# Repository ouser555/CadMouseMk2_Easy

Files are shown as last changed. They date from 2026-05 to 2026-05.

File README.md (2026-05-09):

# CAD Mouse MK2

Watch the build video ↓

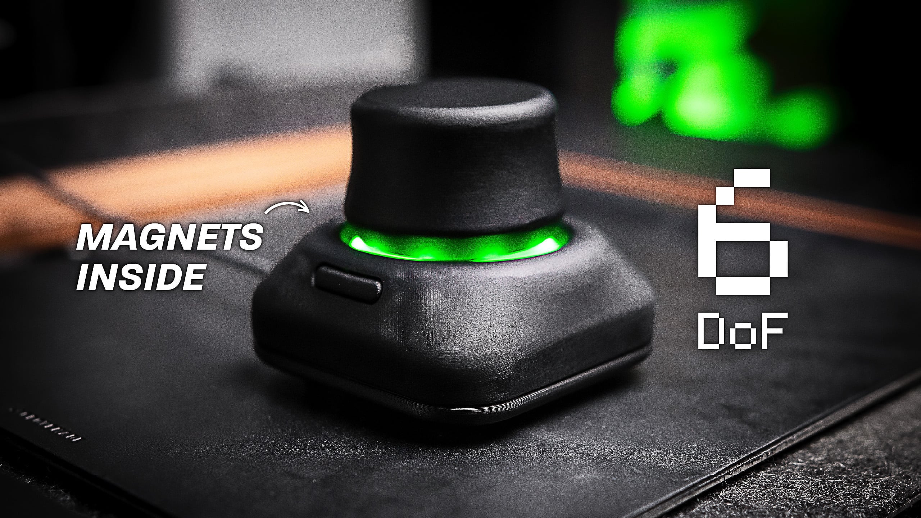
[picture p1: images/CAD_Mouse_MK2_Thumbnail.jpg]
[](https://youtu.be/62xlzGs8LXA)

This is the second iteration of my DIY CAD Mouse, rebuilt to behave like a real 6DoF controller. There are still some motion processing issues, but it's much better than the previous version. It uses a custom PCB with three magnetic sensors, a 3D printed spring, and a redesigned enclosure that is smaller and easier to build.

Build instructions (coming soon)

<sub>⚠️ There have been several comments raising concerns about the longevity of the PETG spring. If it does not last as expected, a revision of the knob design will be needed.</sub>

[][cc-by-nc-sa]

[][cc-by-nc-sa]

[cc-by-nc-sa]: http://creativecommons.org/licenses/by-nc-sa/4.0/
[cc-by-nc-sa-image]: https://licensebuttons.net/l/by-nc-sa/4.0/88x31.png
[cc-by-nc-sa-shield]: https://img.shields.io/badge/License-CC%20BY--NC--SA%204.0-lightgrey.svg

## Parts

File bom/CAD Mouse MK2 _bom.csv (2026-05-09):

Qty | Part | Link
1 | Seeed Studio XIAO RP2040 | https://geni.us/9SqAMi
1 | Assembled Sensor Board with MCU Adapter | https://bit.ly/48rovz3
16 | M3 x 4 Heat-Set Inserts | https://geni.us/s0GG2
10 | M3 x 16 Hexagon Socket Head Cap Screw | https://geni.us/ncMxqyo
5 | M3 x 12 Hexagon Socket Head Cap Screw | https://geni.us/ncMxqyo
1 | M2 x 4 Hexagon Socket Head Cap Screw | https://geni.us/ncMxqyo
6 | 6mm x 3mm Neodymium Magnets | https://geni.us/JU58
4 | Rubber Bumper Feet | https://geni.us/vBw7v

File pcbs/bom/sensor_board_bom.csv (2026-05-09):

Reference Designators | Quantity | Description | Package | Value | Digikey
C1, C2 | 2 | 1 µF ±20% 10V Ceramic Capacitor X7R 1206 (3216 Metric) | CAPC3216X135 | 1uF | 4713-GMC31X7R105M10NTCT-ND
C3, C4, C5, C6, C7, C8, C9, C10, C11, C12, C13, C14, C15, C16, C17 | 15 | 0.1 µF ±20% 16V Ceramic Capacitor X7R 0805 (2012 Metric) | CAPC2012X110 | 100nF | 399-C0805C104K5RACTUCT-ND
C18 | 1 | 22 µF ±20% 25V Ceramic Capacitor X5R 1206 (3216 Metric) | CAPC3216X135 | 22uF | 587-3246-1-ND
D1, D2, D3, D4, D5, D6, D7, D8 | 8 | Addressable Lighting - LED Red, Green, Blue (RGB) 4.00mm L x 2.00mm W | LED_SK6812_SIDE-A | SK6812_SIDE-A | 3147-T4203GRB-12C-61013TU1930CT-ND
J1, J2 | 2 | 6 Position Header Connector 0.079" (2.00mm) Through Hole Gold | CONN3X2_NPPN032AFCN-RC_SUL | NPPN032AFCN-RCCONN3X2_NPPN032AFCN-RC_SUL | S5750-03-ND
MAG1, MAG2, MAG3 | 3 | Hall Effect Sensor Axis PG-TSOP6-6-8 (TLI493D-A2B6) | SOP95P280X110-6N-V | TLI493D-A2B6 | TLI493DA2B6HTSA1CT-ND
R1, R2 | 2 | 10 kOhms ±1% 0.125W, 1/8W Chip Resistor 0805 (2012 Metric) Automotive AEC-Q200 Thick Film | RESC2012X65 | 10K | RMCF0805FT10K0CT-ND
RN1 | 1 | 10k Ohm ±5% 62.5mW Power Per Element Isolated 4 Resistor Network/Array ±200ppm/°C 1206 (3216 Metric), Convex, Long Side Terminals | RESCAF80P320X160X60-8N | CAY16-103J4LF | CAY16-103J4LFCT-ND
S1, S2 | 2 | Tactile Switch SPST-NO Side Actuated Surface Mount, Right Angle | SW_TS32-7-35-BK-160-RA-SMT-TR | TS32-7-35-BK-160-RA-SMT-TR | 2223-TS32-7-35-BK-160-RA-SMT-TRCT-ND
U1, U2, U3, U4 | 4 | Power Switch/Driver 1:1 N/P-Channel 1A TSOT-25 | SOT95P280X100-5N | AP22816BKEWT-7 | 31-AP22816AKEWT-7CT-ND
U5 | 1 | Buffer, Non-Inverting 1 Element 1 Bit per Element 3-State Output SOT-23-5 | SOT95P280X145-5N | SN74AHCT1G125DBVR | 296-4708-1-ND
H1, H2 | 2 | Connector Header Through Hole 6 position 0.079" (2.00mm) | CONN3X2_NRPN032PAEN | NRPN032PAEN-RC | S5801-03-ND

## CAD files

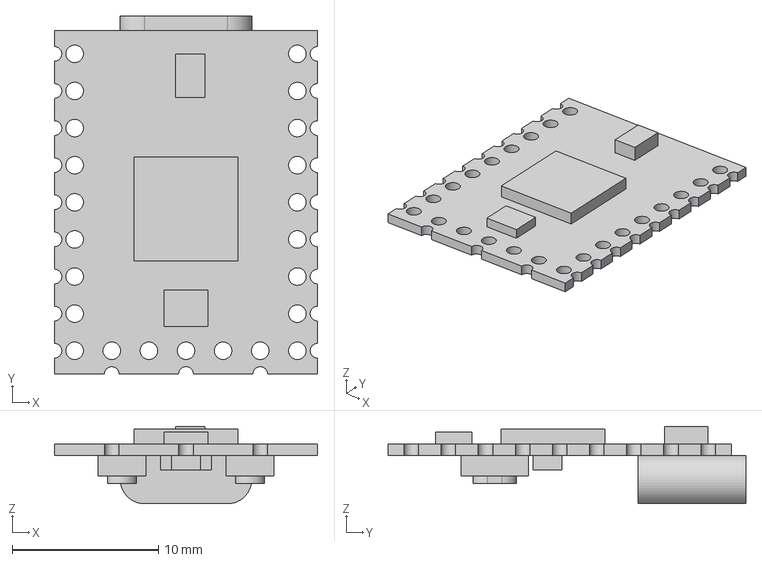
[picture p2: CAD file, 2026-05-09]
enclosure/fusion/rp2040zero.step
18.0 x 24.5 x 5.30 mm

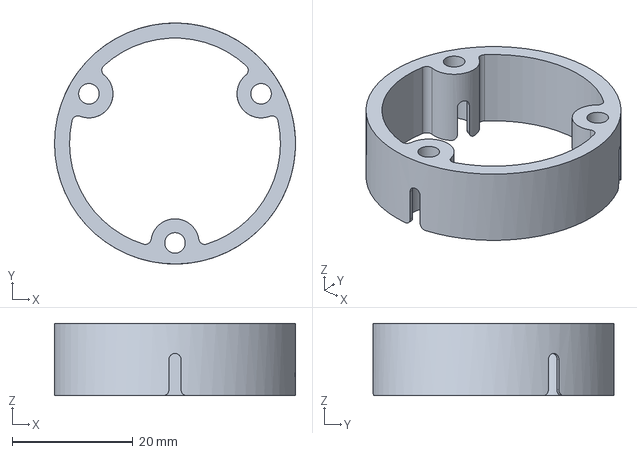
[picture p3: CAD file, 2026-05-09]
enclosure/fusion/Magnets Holder.step
40.0 x 40.0 x 12.0 mm

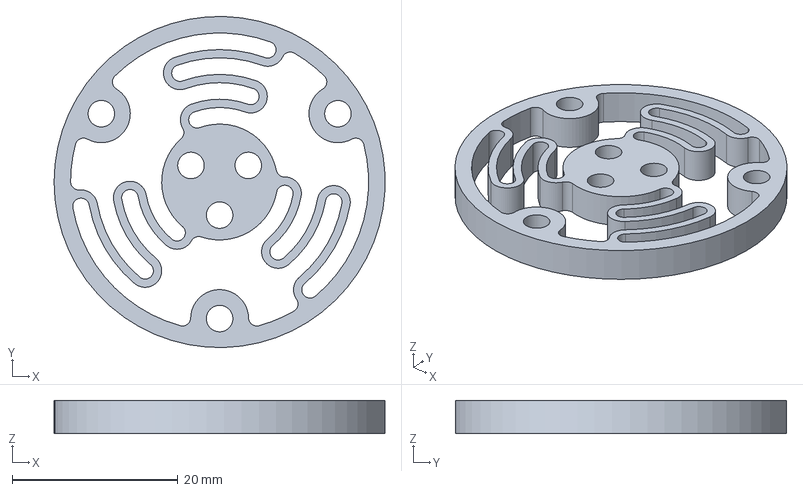
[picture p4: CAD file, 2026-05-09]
enclosure/fusion/newSpring.step
40.0 x 40.0 x 4.00 mm

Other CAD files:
enclosure/fusion/Spring (parametric).f3d

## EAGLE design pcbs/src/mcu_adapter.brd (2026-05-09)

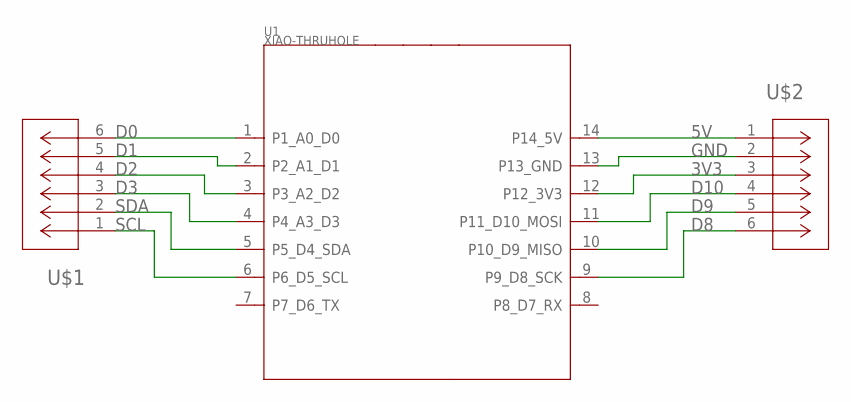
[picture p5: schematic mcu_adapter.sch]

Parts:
U1: XIAO-THRUHOLE; XIAO-GENERIC-THRUHOLE-MODULE14P-2.54-21X17.8MM
U$1, U$2: NRPN032PAEN-RC; CONN3X2_NRPN032PAEN-RC

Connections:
3V3: U1.12 (P12_3V3), U$2.3
5V: U1.14 (P14_5V), U$2.1
D0: U1.1 (P1_A0_D0), U$1.6
D1: U1.2 (P2_A1_D1), U$1.5
D2: U1.3 (P3_A2_D2), U$1.4
D3: U1.4 (P4_A3_D3), U$1.3
D8: U1.9 (P9_D8_SCK), U$2.6
D9: U1.10 (P10_D9_MISO), U$2.5
D10: U1.11 (P11_D10_MOSI), U$2.4
GND: U1.13 (P13_GND), U$2.2
SCL: U1.6 (P6_D5_SCL), U$1.1
SDA: U1.5 (P5_D4_SDA), U$1.2

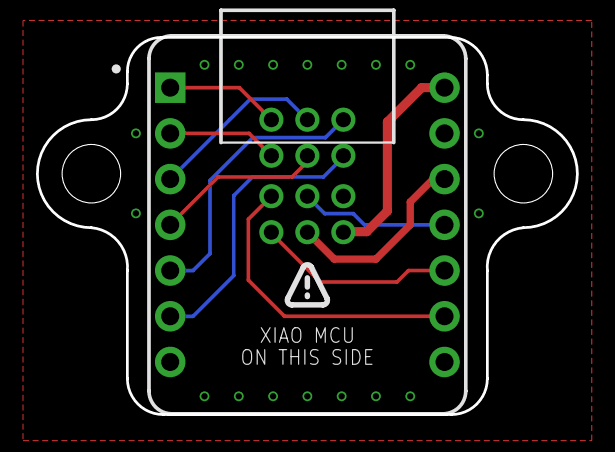
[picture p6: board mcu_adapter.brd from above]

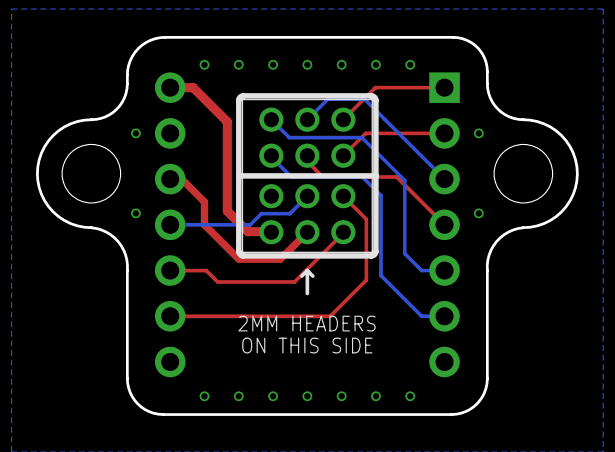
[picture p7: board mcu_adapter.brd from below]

Board: 2 copper layers, 30.0 x 21.0 mm, 3 parts (2 on the bottom side), 12 nets.

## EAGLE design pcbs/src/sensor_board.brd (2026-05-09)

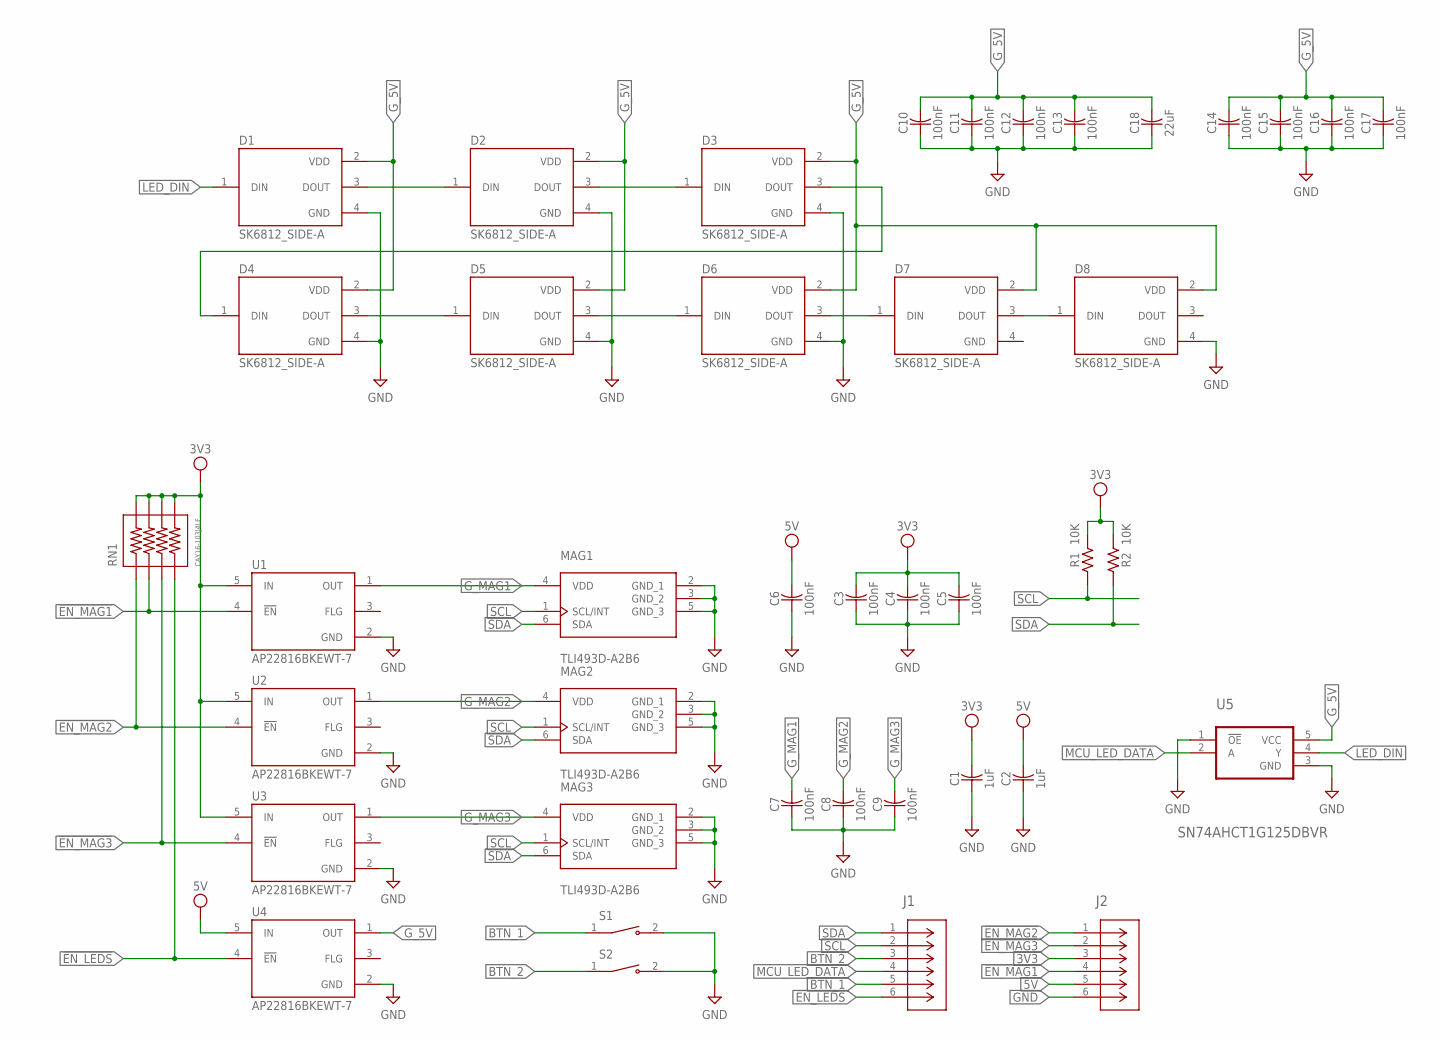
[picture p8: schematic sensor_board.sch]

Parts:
C1, C2: 1uF; CAPC3216X135
C3, C4, C5, C6, C7, C8, C9, C10, C11, C12, C13, C14, C15, C16, C17: 100nF; CAPC2012X110
C18: 22uF; CAPC3216X135
D1, D2, D3, D4, D5, D6, D7, D8: SK6812_SIDE-A; LED_SK6812_SIDE-A
J1, J2: NPPN032AFCN-RCCONN3X2_NPPN032AFCN-RC_SUL; CONN3X2_NPPN032AFCN-RC_SUL
MAG1, MAG2, MAG3: TLI493D-A2B6; SOP95P280X110-6N-V
R1, R2: 10K; RESC2012X65
RN1: CAY16-103J4LF; RESCAF80P320X160X60-8N
S1, S2: TS32-7-35-BK-160-RA-SMT-TR; SW_TS32-7-35-BK-160-RA-SMT-TR
U1, U2, U3, U4: AP22816BKEWT-7; SOT95P280X100-5N
U5: SN74AHCT1G125DBVR; SOT95P280X145-5N

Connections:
3V3: C1.2, C3.2, C4.2, C5.2, J2.3, R1.2, R2.2, RN1.5, RN1.6, RN1.7, RN1.8, U1.5 (IN), U2.5 (IN), U3.5 (IN)
5V: C2.2, C6.2, J2.5, U4.5 (IN)
!EN_LEDS: J1.6, RN1.4, U4.4 (!EN)
!EN_MAG1: J2.4, RN1.2, U1.4 (!EN)
!EN_MAG2: J2.1, RN1.1, U2.4 (!EN)
!EN_MAG3: J2.2, RN1.3, U3.4 (!EN)
BTN_1: J1.5, S1.1
BTN_2: J1.3, S2.1
GND: C1.1, C2.1, C3.1, C4.1, C5.1, C6.1, C7.1, C8.1, C9.1, C10.1, C11.1, C12.1, C13.1, C14.1, C15.1, C16.1, C17.1, C18.1, D1.4 (GND), D2.4 (GND), D3.4 (GND), D4.4 (GND), D5.4 (GND), D6.4 (GND), D7.4 (GND), D8.4 (GND), J2.6, MAG1.2 (GND_1), MAG1.3 (GND_2), MAG1.5 (GND_3), MAG2.2 (GND_1), MAG2.3 (GND_2), MAG2.5 (GND_3), MAG3.2 (GND_1), MAG3.3 (GND_2), MAG3.5 (GND_3), S1.2, S2.2, U1.2 (GND), U2.2 (GND), U3.2 (GND), U4.2 (GND), U5.1 (!OE), U5.3 (GND)
G_5V: C10.2, C11.2, C12.2, C13.2, C14.2, C15.2, C16.2, C17.2, C18.2, D1.2 (VDD), D2.2 (VDD), D3.2 (VDD), D4.2 (VDD), D5.2 (VDD), D6.2 (VDD), D7.2 (VDD), D8.2 (VDD), U4.1 (OUT), U5.5 (VCC)
G_MAG1: C7.2, MAG1.4 (VDD), U1.1 (OUT)
G_MAG2: C8.2, MAG2.4 (VDD), U2.1 (OUT)
G_MAG3: C9.2, MAG3.4 (VDD), U3.1 (OUT)
LED_DIN: D1.1 (DIN), U5.4 (Y)
MCU_LED_DATA: J1.4, U5.2 (A)
unnamed: D1.3 (DOUT), D2.1 (DIN)
unnamed: D2.3 (DOUT), D3.1 (DIN)
unnamed: D6.3 (DOUT), D7.1 (DIN)
unnamed: D3.3 (DOUT), D4.1 (DIN)
unnamed: D4.3 (DOUT), D5.1 (DIN)
unnamed: D5.3 (DOUT), D6.1 (DIN)
unnamed: D7.3 (DOUT), D8.1 (DIN)
SCL: J1.2, MAG1.1 (SCL/INT), MAG2.1 (SCL/INT), MAG3.1 (SCL/INT), R1.1
SDA: J1.1, MAG1.6 (SDA), MAG2.6 (SDA), MAG3.6 (SDA), R2.1

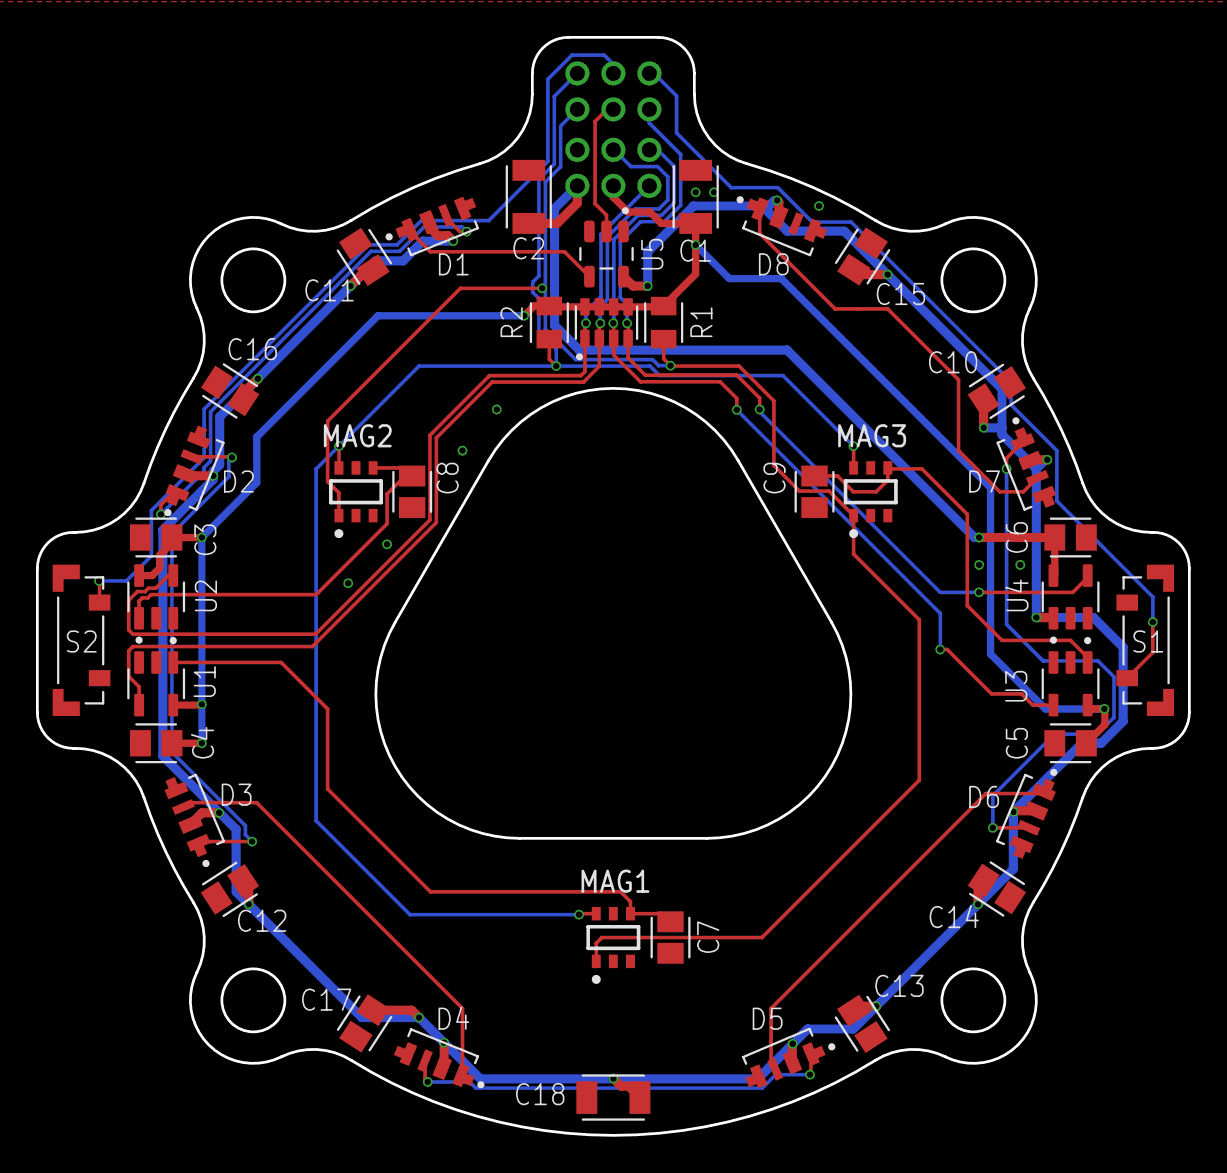
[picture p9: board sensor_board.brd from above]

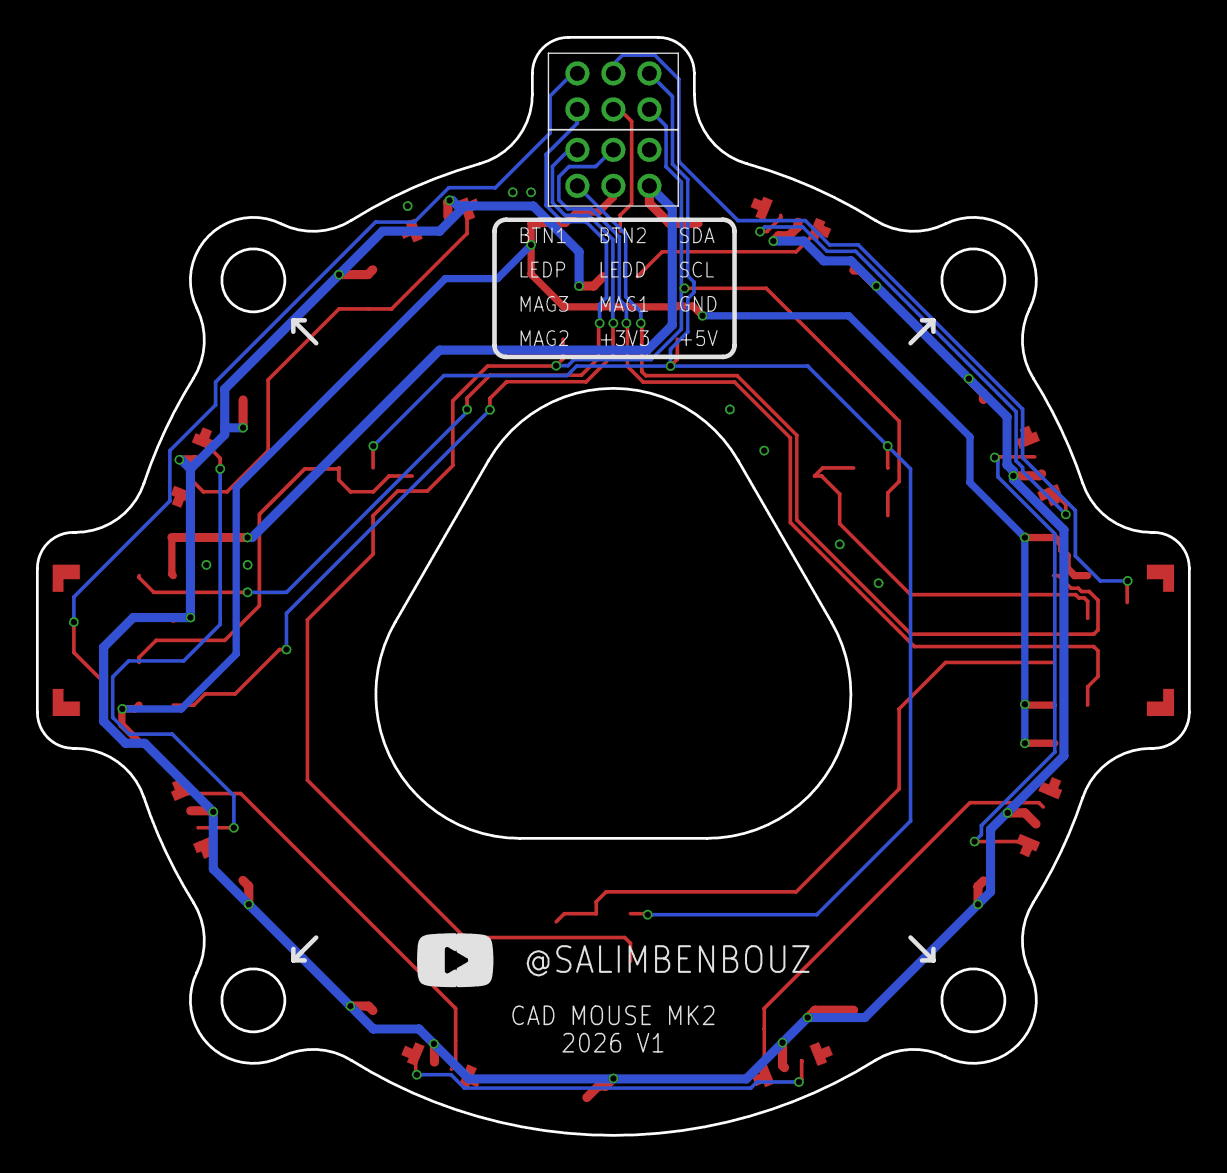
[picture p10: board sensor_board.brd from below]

Board: 2 copper layers, 64.0 x 61.0 mm, 41 parts (2 on the bottom side), 24 nets.

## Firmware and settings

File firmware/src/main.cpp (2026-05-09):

#include <Arduino.h>

#include "Config.h"
#include "Controllers.h"
#include "StateMachine.h"

InputController inputController;
LEDController ledController;
SensorController sensorController;
MotionController motionController;
HIDController hidController;
TelemetryController telemetryController;

void setup() {
  // Initialize USB HID first
  hidController.begin();

  if (Config::ENABLE_TELEMETRY) {
    Serial.begin(115200);
    delay(200);
  }

delay(1000);
//Serial.println(">start!!!!!A:");
//Serial.println(">start!!!!!A:");

  inputController.begin();
  ledController.begin();

Serial.println(">sensor begin");
  sensorController.begin();

Serial.println(">motion begin");
  motionController.reset();

Serial.println(">telemetry begin");
  telemetryController.begin();

Serial.println(">calibrating");
  stateMachine.changeState(&StateMachine::calibratingState);

  //Serial.println(">I2C1:");
  //Serial.println(SDA);
  //Serial.println(SCL);
}

void loop() {
  hidController.task();
  stateMachine.update();
  //Serial.println(">main loop:");
}

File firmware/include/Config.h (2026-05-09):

#pragma once

#include <Arduino.h>

namespace Config {

const bool ENABLE_TELEMETRY = true;
//const bool ENABLE_TELEMETRY = false;

// Hardware pins (XIAO RP2040)
//const int PIN_RIGHT_BTN = D0;
//const int PIN_LED_LS = D1;
//const int PIN_LEFT_BTN = D2;
//const int PIN_LED_DATA = D3;

//const int PIN_MAG1_LS = D10;
//const int PIN_MAG2_LS = D9;
//const int PIN_MAG3_LS = D8;

// Hardware pins (RP2040 ZERO)
const int PIN_RIGHT_BTN = 0;
const int PIN_LEFT_BTN = 2;
const int PIN_BOOT_BTN = 25; //bootloader pin
const int PIN_LED_DATA = 3;
//const int PIN_LED_DATA = 16; //rp2040_zero onboard RGB
const int PIN_LED_LS = 1;
const int PIN_MAG1_LS = 29;
const int PIN_MAG2_LS = 28;
const int PIN_MAG3_LS = 27;

// Samples for calibration offset
const int ZERO_SAMPLES = 200;

// Gains and sign fixes
const float GAIN_T[3] = {28.0, 28.0, 24.0};
const float GAIN_R[3] = {18.0, 18.0, 20.0};
const int SIGN_AXIS[6] = {-1, +1, -1, +1, +1, +1};

// Dead zones
//const float DEAD_T = 16.0;
//const float DEAD_T = 8.0;
const float DEAD_T = 4.0;
//const float DEAD_R = 20.0;
//const float DEAD_R = 10.0;
const float DEAD_R = 5.0;

// Sensitivity curve exponent.
// 1.0 = linear, 3.0 = cubic (fine control at small deflections, fast at large).
const float SENSITIVITY_EXP = 3.0;
//const float SENSITIVITY_EXP = 2.5;

// Sensor validation: reject any frame where a magnetic axis reads beyond
// this magnitude. EXTRA_SHORT_RANGE peaks around 130 mT; anything past
// this bound indicates a read fault or corrupted frame.
const float SENSOR_SANITY_LIMIT_MT = 500.0;

// Smoothing
const float SMOOTH_TAU_S = 0.08;

// Final axis output range
const float AXIS_LIMIT = 350.0;

// RGB LEDs
const int LED_COUNT = 8;
const int LED_BRIGHTNESS = 40;
//const unsigned long LED_IDLE_COLOR = 0x00FF00; //green
const unsigned long LED_IDLE_COLOR = 0x800080; // purple
//const unsigned long LED_IDLE_COLOR = 0x6B3FA0; // royal purple
//const unsigned long LED_IDLE_COLOR = 0xE6E6FA; // Lavender
//const unsigned long LED_CALIBRATING_COLOR = 0x0000FF; //blue
//const unsigned long LED_CALIBRATING_COLOR = 0xFFDF00; // gold yellow
//const unsigned long LED_CALIBRATING_COLOR = 0xFFD700; // gold
const unsigned long LED_CALIBRATING_COLOR = 0xFFBF00; // amber
const unsigned long LED_ERROR_COLOR = 0xFF0000;

// FSM timing
const long IDLE_SLEEP_TIMEOUT_MS = 2 * 60 * 1000;


// Sleep-mode wake on knob motion. Sensors stay powered while asleep,
// so we can poll them at a slow cadence and wake Idle if any axis
// deviates from the calibrated baseline by more than the threshold.
const unsigned long SLEEP_WAKE_POLL_MS = 100;
const float SLEEP_WAKE_THRESHOLD_MT = 5.0;
}  // namespace Config

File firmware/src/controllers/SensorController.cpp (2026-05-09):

#include "controllers/SensorController.h"

#include "Config.h"

using namespace ifx::tlx493d;

SensorController::SensorController()
    : mag1Sensor_(Wire, TLx493D_IIC_ADDR_A0_e),
      mag2Sensor_(Wire, TLx493D_IIC_ADDR_A0_e),
      mag3Sensor_(Wire, TLx493D_IIC_ADDR_A0_e) {}

void SensorController::powerOff(int pin) { digitalWrite(pin, LOW); }

void SensorController::powerOn(int pin) {
  digitalWrite(pin, HIGH);
  delay(5);
}

void SensorController::begin() {

  pinMode(Config::PIN_MAG1_LS, OUTPUT);
  pinMode(Config::PIN_MAG2_LS, OUTPUT);
  pinMode(Config::PIN_MAG3_LS, OUTPUT);

  // All three rails are pulled high in hardware, so force them all off first
  // before bringing sensors up one-by-one for address assignment.

  powerOff(Config::PIN_MAG1_LS);
  powerOff(Config::PIN_MAG2_LS);
  powerOff(Config::PIN_MAG3_LS);

  Wire.setSDA(4);
  Wire.setSCL(5);
  
  Wire.begin();
  Wire.setClock(400000);
  //Wire.setClock(100000);

  delay(500);

  powerOn(Config::PIN_MAG1_LS);
  delay(20);
  mag1Sensor_.begin(true, false, false, true);
  mag1Sensor_.setIICAddress(TLx493D_IIC_ADDR_A2_e);
  mag1Sensor_.setSensitivity(TLx493D_EXTRA_SHORT_RANGE_e);
  delay(10);

  powerOn(Config::PIN_MAG2_LS);
  delay(20);
  mag2Sensor_.begin(true, false, false, true);
  mag2Sensor_.setIICAddress(TLx493D_IIC_ADDR_A1_e);
  mag2Sensor_.setSensitivity(TLx493D_EXTRA_SHORT_RANGE_e);
  delay(10);

  powerOn(Config::PIN_MAG3_LS);
  delay(20);
  mag3Sensor_.begin(true, false, false, true);
  mag3Sensor_.setSensitivity(TLx493D_EXTRA_SHORT_RANGE_e);
  delay(10);
}

//void SensorController::readRaw(float out[9]) {
bool SensorController::readRaw(float out[9]) {
  double mag1x = 0, mag1y = 0, mag1z = 0, temp1 = 0;
  double mag2x = 0, mag2y = 0, mag2z = 0, temp2 = 0;
  double mag3x = 0, mag3y = 0, mag3z = 0, temp3 = 0;

  mag1Sensor_.getMagneticFieldAndTemperature(&mag1x, &mag1y, &mag1z, &temp1);
  mag2Sensor_.getMagneticFieldAndTemperature(&mag2x, &mag2y, &mag2z, &temp2);
  mag3Sensor_.getMagneticFieldAndTemperature(&mag3x, &mag3y, &mag3z, &temp3);

  // MAG1 = bottom, MAG2 = top left, MAG3 = top right.
  out[0] = mag1x;
  out[1] = mag1y;
  out[2] = mag1z;
  out[3] = mag2x;
  out[4] = mag2y;
  out[5] = mag2z;
  out[6] = mag3x;
  out[7] = mag3y;
  out[8] = mag3z;
#if 0
  Serial.print(">mag1_x:");
  Serial.println(out[0]);
  Serial.print(">mag1_y:");
  Serial.println(out[1]);
  Serial.print(">mag1_z:");
  Serial.println(out[2]);
  Serial.print(">mag2_x:");
  Serial.println(out[3]);
  Serial.print(">mag2_y:");
  Serial.println(out[4]);
  Serial.print(">mag2_z:");
  Serial.println(out[5]);
  Serial.print(">mag3_x:");
  Serial.println(out[6]);
  Serial.print(">mag3_y:");
  Serial.println(out[7]);
  Serial.print(">mag3_z:");
  Serial.println(out[8]);

#endif
#if 1
  // Validate: reject frames with any non-finite value (NaN would
  // silently slip past a magnitude check and permanently poison the
  // Kalman state), any axis outside the sensor's sane range, or a
  // sensor that returned all-zero across its three axes (the library
  // leaves the initial zeros in place on I2C failure).
  for (int i = 0; i < 9; i++) {
    if (!isfinite(out[i]) ||
        fabsf(out[i]) > Config::SENSOR_SANITY_LIMIT_MT) {
      return false;
    }
  }
  // Check for dead sensor (all three axes exactly zero)
  for (int s = 0; s < 3; s++) {
    const int base = s * 3;
    if (out[base] == 0.0f && out[base + 1] == 0.0f && out[base + 2] == 0.0f) {
      return false;
    }
  }
#endif
  return true;
}

void SensorController::beginCalibration() {
  calibrationActive_ = true;
  calibrationDone_ = false;
  calibrationSamples_ = 0;
  lastCalibrationSampleMs_ = 0;
  for (int i = 0; i < 9; i++) {
    calibrationSum_[i] = 0.0;
  }
}

void SensorController::updateCalibration() {
  if (!calibrationActive_) {
    return;
  }

  const unsigned long now = millis();
  if (lastCalibrationSampleMs_ != 0 &&
      (now - lastCalibrationSampleMs_) < 10) {
    return;
  }
  lastCalibrationSampleMs_ = now;

  float raw[9] = {};
  readRaw(raw);

  for (int i = 0; i < 9; i++) {
    calibrationSum_[i] += raw[i];
  }

  calibrationSamples_++;
  if (calibrationSamples_ < Config::ZERO_SAMPLES) {
    return;
  }

  for (int i = 0; i < 9; i++) {
    baseline_[i] = calibrationSum_[i] / Config::ZERO_SAMPLES;
  }

  calibrationActive_ = false;
  calibrationDone_ = true;
}

bool SensorController::calibrationDone() const { return calibrationDone_; }

const float* SensorController::baseline() const { return baseline_; }

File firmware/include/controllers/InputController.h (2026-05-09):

#pragma once

#include <Arduino.h>
#include <AceButton.h>

class InputController {
 public:
  InputController();
  void begin();
  void update();

  uint16_t buttonBits() const;
  bool takeCalibrationRequest();
  bool takeActivity();

 private:
  static void handleButtonEvent(ace_button::AceButton* button, uint8_t eventType,
                                uint8_t buttonState);
  void onButtonEvent(ace_button::AceButton* button, uint8_t eventType);
  bool areBothPressed() const;

  ace_button::AceButton leftBtn_;
  ace_button::AceButton rightBtn_;
  ace_button::AceButton bootBtn_; //bootloader

  bool calibrationRequested_ = false;
  bool hadActivity_ = false;
  unsigned long bothHeldStartMs_ = 0;
  bool calibrationHoldFired_ = false;
  bool leftPressed_ = false;
  bool rightPressed_ = false;

  static InputController* instance_;
};

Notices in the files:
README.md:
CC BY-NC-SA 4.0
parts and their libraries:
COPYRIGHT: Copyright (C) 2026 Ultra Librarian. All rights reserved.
